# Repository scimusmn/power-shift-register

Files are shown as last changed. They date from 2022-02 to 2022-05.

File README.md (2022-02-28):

Power Shift Registers
=====================

Modular power shift register boards, based on the [TPIC6A595NE] chips.

These boards come in two varieties: *mother boards*, which include a Metro Mini and lack a data in port, and *daughter boards*, which are intended to have data shifted in to them. These two designs exist so that for applications that require only shift registers no additional hardware is necessary, but custom boards can still be designed to control the daughter boards.

[TPIC6A595NE]: https://www.ti.com/lit/ds/symlink/tpic6a595.pdf

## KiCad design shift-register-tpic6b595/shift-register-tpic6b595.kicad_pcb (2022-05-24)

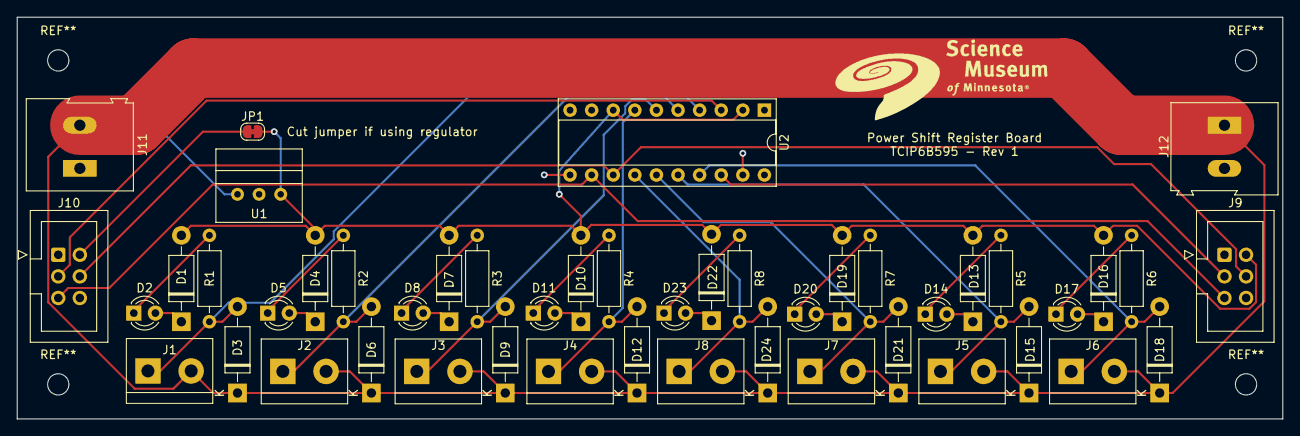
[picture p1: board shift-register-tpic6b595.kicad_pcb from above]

Board: 2 copper layers, 148.8 x 47.2 mm, 47 parts (0 on the bottom side), 32 nets.

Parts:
D1, D3, D4, D6, D7, D9, D10, D12, D13, D15, D16, D18, D19, D21, D22, D24: 1N4001; D_DO-41_SOD81_P10.16mm_Horizontal
D2, D5, D8, D11, D14, D17, D20, D23: LED; LED_D3.0mm
J1, J2, J3, J4, J5, J6, J7, J8: Screw_Terminal_01x02; TerminalBlock_bornier-2_P5.08mm
J9, J10: Conn_02x03_Odd_Even; IDC-Header_2x03_P2.54mm_Vertical
J11, J12: Screw_Terminal_01x02; TerminalBlock-2_P5.08mm_large
JP1: SolderJumper_2_Bridged; SolderJumper-2_P1.3mm_Bridged_RoundedPad1.0x1.5mm
R1, R2, R3, R4, R5, R6, R7, R8: R; Resistor_L6.3mm_D2.5mm_P10.16mm_Horizontal
U1: I50115
U2: TPIC6B595; DIP-20_W7.62mm_Socket

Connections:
+5V: D1.2 (A), D4.2 (A), D7.2 (A), D10.2 (A), D13.2 (A), D16.2 (A), D19.2 (A), D22.2 (A), J9.2, JP1.2 (B), U1.3 (+5V), U2.2 (VCC), U2.8 (SRCLR)
+VDC: D3.1 (K), D6.1 (K), D9.1 (K), D12.1 (K), D15.1 (K), D18.1 (K), D21.1 (K), D24.1 (K), J1.2, J2.2, J3.2, J4.2, J5.2, J6.2, J7.2, J8.2, J11.2, J12.1, U1.1 (PWR)
/CLOCK: J9.4, J10.4, U2.13 (SRCK)
/D0: D3.2 (A), J1.1, R1.2, U2.4 (DRAIN0)
/D1: D6.2 (A), J2.1, R2.2, U2.5 (DRAIN1)
/D2: D9.2 (A), J3.1, R3.2, U2.6 (DRAIN2)
/D3: D12.2 (A), J4.1, R4.2, U2.7 (DRAIN3)
/D4: D24.2 (A), J8.1, R8.2, U2.14 (DRAIN4)
/D5: D21.2 (A), J7.1, R7.2, U2.15 (DRAIN5)
/D6: D15.2 (A), J5.1, R5.2, U2.16 (DRAIN6)
/D7: D18.2 (A), J6.1, R6.2, U2.17 (DRAIN7)
/LATCH: J9.5, J10.5, U2.12 (RCK)
/SERIN: J10.3, U2.3 (SERIN)
/SEROUT: J9.3, U2.18 (SEROUT)
GND: J9.1, J10.1, J11.1, J12.2, U1.2 (GND), U2.10 (GND), U2.11 (GND), U2.19 (GND)
unnamed: D1.1 (K), D2.2 (A)
unnamed: D2.1 (K), R1.1
unnamed: D4.1 (K), D5.2 (A)
unnamed: D5.1 (K), R2.1
unnamed: D7.1 (K), D8.2 (A)
unnamed: D8.1 (K), R3.1
unnamed: D10.1 (K), D11.2 (A)
unnamed: D11.1 (K), R4.1
unnamed: D13.1 (K), D14.2 (A)
unnamed: D14.1 (K), R5.1
unnamed: D16.1 (K), D17.2 (A)
unnamed: D17.1 (K), R6.1
unnamed: D19.1 (K), D20.2 (A)
unnamed: D20.1 (K), R7.1
unnamed: D22.1 (K), D23.2 (A)
unnamed: D23.1 (K), R8.1
unnamed: J10.2, JP1.1 (A)

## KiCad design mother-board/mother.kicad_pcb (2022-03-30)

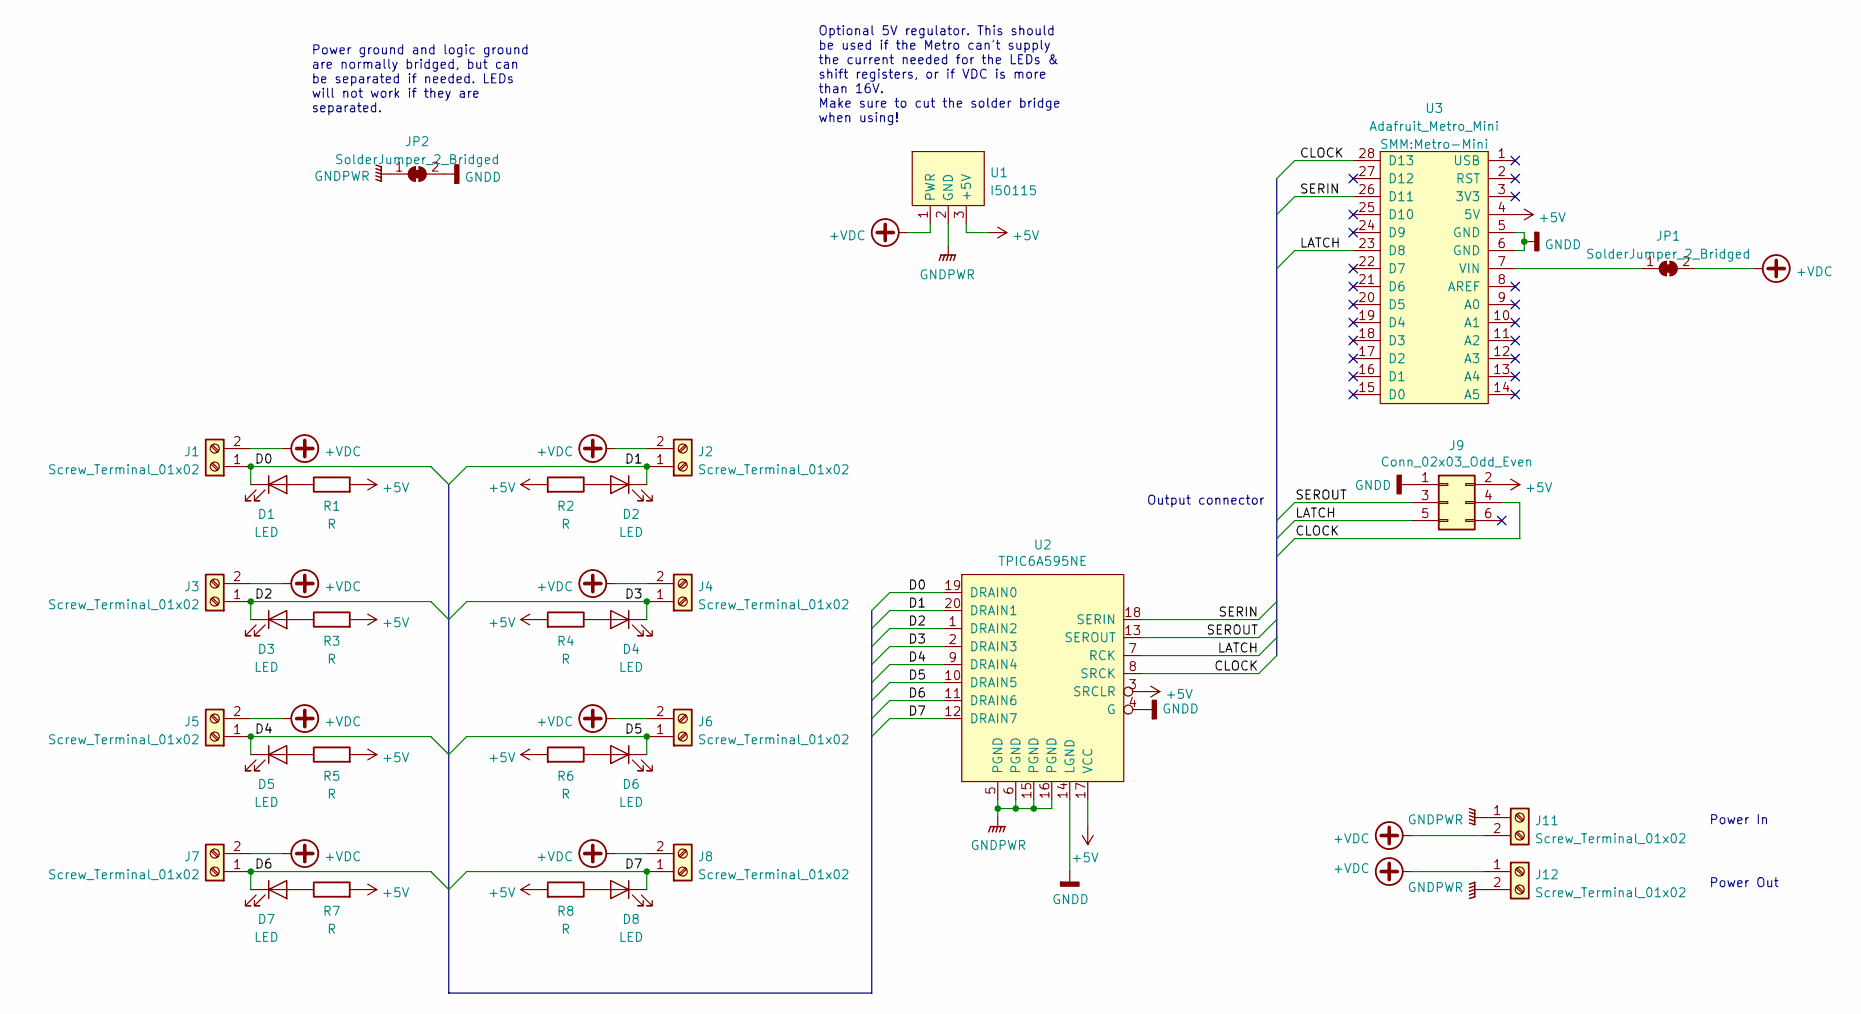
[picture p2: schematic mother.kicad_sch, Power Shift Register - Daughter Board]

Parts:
D1, D2, D3, D4, D5, D6, D7, D8: LED; LED_D3.0mm
J1, J2, J3, J4, J5, J6, J7, J8: Screw_Terminal_01x02; TerminalBlock_bornier-2_P5.08mm
J9: Conn_02x03_Odd_Even; IDC-Header_2x03_P2.54mm_Vertical
J11, J12: Screw_Terminal_01x02; TerminalBlock-2_P5.08mm_large
JP1, JP2: SolderJumper_2_Bridged; SolderJumper-2_P1.3mm_Bridged_RoundedPad1.0x1.5mm
R1, R2, R3, R4, R5, R6, R7, R8: R; R_Axial_DIN0207_L6.3mm_D2.5mm_P10.16mm_Horizontal
U1: I50115
U2: TPIC6A595NE; DIP-20_W7.62mm_Socket
U3: Adafruit_Metro_Mini; Metro-Mini

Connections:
+5V: J9.2, R1.2, R2.2, R3.2, R4.2, R5.2, R6.2, R7.2, R8.2, U1.3 (+5V), U2.3 (SRCLR), U2.17 (VCC), U3.4 (5V)
+VDC: J1.2, J2.2, J3.2, J4.2, J5.2, J6.2, J7.2, J8.2, J11.2, J12.1, JP1.2 (B), U1.1 (PWR)
/CLOCK: J9.4, U2.8 (SRCK), U3.28 (D13)
/D0: D1.1 (K), J1.1, U2.19 (DRAIN0)
/D1: D2.1 (K), J2.1, U2.20 (DRAIN1)
/D2: D3.1 (K), J3.1, U2.1 (DRAIN2)
/D3: D4.1 (K), J4.1, U2.2 (DRAIN3)
/D4: D5.1 (K), J5.1, U2.9 (DRAIN4)
/D5: D6.1 (K), J6.1, U2.10 (DRAIN5)
/D6: D7.1 (K), J7.1, U2.11 (DRAIN6)
/D7: D8.1 (K), J8.1, U2.12 (DRAIN7)
/LATCH: J9.5, U2.7 (RCK), U3.23 (D8)
/SERIN: U2.18 (SERIN), U3.26 (D11)
/SEROUT: J9.3, U2.13 (SEROUT)
GNDD: J9.1, JP2.2 (B), U2.4 (G), U2.14 (LGND), U3.5 (GND), U3.6 (GND)
GNDPWR: J11.1, J12.2, JP2.1 (A), U1.2 (GND), U2.5 (PGND), U2.6 (PGND), U2.15 (PGND), U2.16 (PGND)
unnamed: D1.2 (A), R1.1
unnamed: D2.2 (A), R2.1
unnamed: D3.2 (A), R3.1
unnamed: D4.2 (A), R4.1
unnamed: D5.2 (A), R5.1
unnamed: D6.2 (A), R6.1
unnamed: D7.2 (A), R7.1
unnamed: D8.2 (A), R8.1
unnamed: JP1.1 (A), U3.7 (VIN)

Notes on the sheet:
Power Out
Output connector
Power ground and logic ground are normally bridged, but can be separated if needed. LEDs will not work if they are separated.
Optional 5V regulator. This should be used if the Metro can't supply the current needed for the LEDs & shift registers, or if VDC is more than 16V. Make sure to cut the solder bridge when using!
Power In

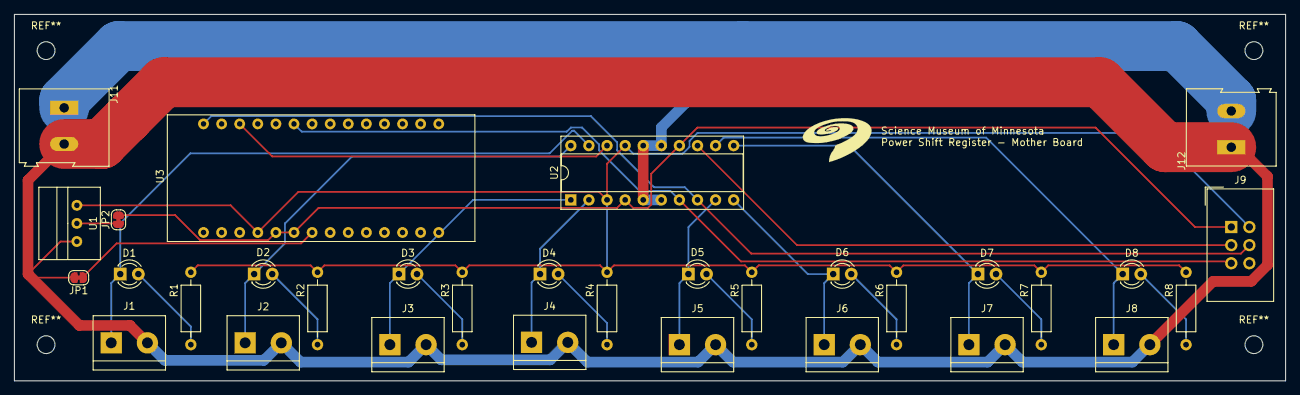
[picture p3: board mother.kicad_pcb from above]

Board: 2 copper layers, 178.4 x 51.4 mm, 32 parts (0 on the bottom side), 25 nets.

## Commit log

2022-03-08 add basic mother schematic
    [mother-board.kicad_pcb, mother-board.kicad_sch, mother-board.sch]
2022-03-08 add all footprints and netlist
    [mother-board.kicad_sch]
2022-03-18 add daughter board
    [daughter.kicad_pcb, daughter.kicad_sch, mother-board.kicad_pcb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]
2022-03-30 add rev 0 boards
    [daughter-B_Cu.gbl, daughter-B_Mask.gbs, daughter-B_Paste.gbp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]
2022-05-24 add tpic6b595 board
    [daughter-B_Cu.gbl, daughter-B_Mask.gbs, daughter-B_Paste.gbp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]
